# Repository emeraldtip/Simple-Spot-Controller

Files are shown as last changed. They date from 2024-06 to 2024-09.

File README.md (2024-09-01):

# Simple Spot Controller
A small, very basic and simple to use Arduino-based DMX spot light controller.
Made to control 6 Cameo TS 60 W RGBW WH theatre spotlights at my school for ceremonial events.
Currently allows you to adjust brightess and temperature of RGBW spotlights with a master dimmer channel.

## Materials used
- 1x Cheap knockoff Arduino (USB type B 2.0 port, ATmega328P CH340 and some extra pin holes next to ICSP pins (GND and 5V for easier soldering))

  Knockoff arduino

- 2x square ACP 47K potentiometers with a rectangular hole stolen from old in-floor heating controller (resistance doesn't really matter much on arduino, you could use any resistance pot just smaller resistance pots use more power)

  ACP potentiometer

- 1x MAX485 chip (as one wasn't available near me and the size is too small to solder to easily without a breakout board, so I bought a cheap USB-RS485 Adapter and soldered wires to the MAX485 on there)
- Female end of an XLR cable
- Wires
- 3D printer plastic (multicolor if you want to be fancy)
- Some small screws (you can screw M3 screws into the posts on the lid or use wood screws or something)

## Code
The code uses the DmxSimple arduino library to write DMX values and just reads potentiometer values to control the global dimmer brightness and the RGB channel values, which shift the color temp of the lights.

## Wiring
This fritzing image pretty much sums it up.

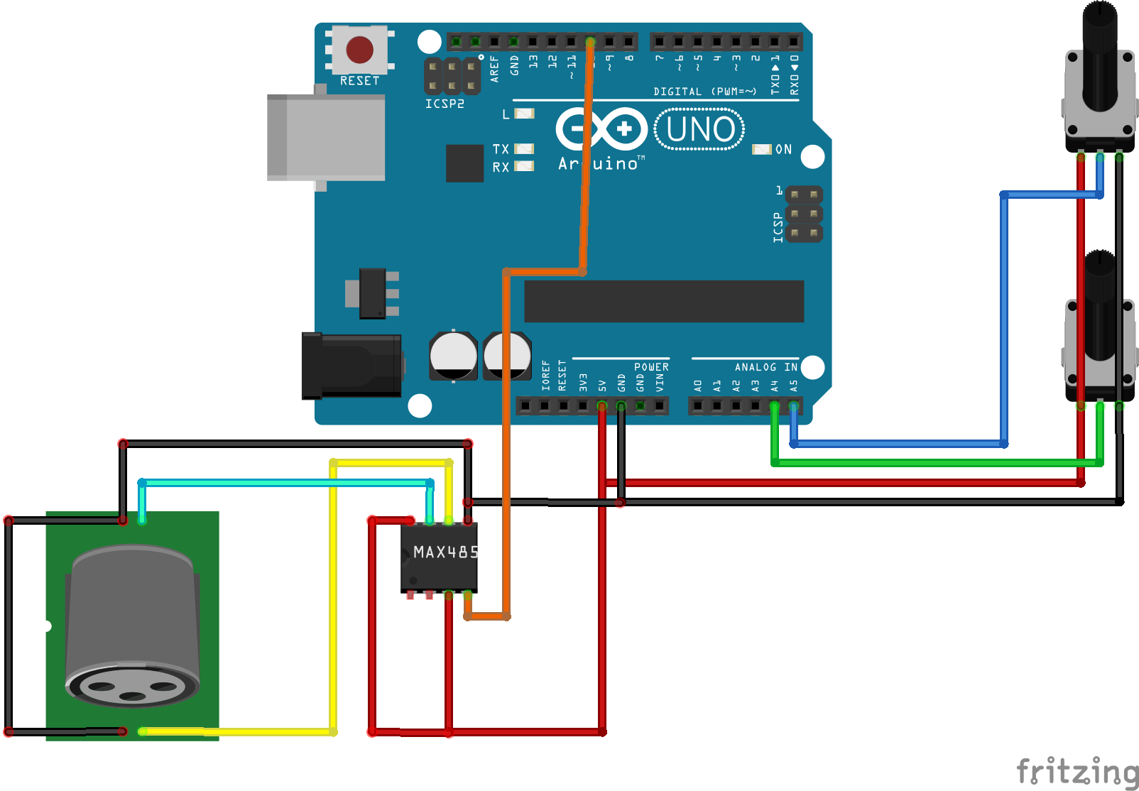
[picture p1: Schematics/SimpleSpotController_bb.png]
Fritzing schematic


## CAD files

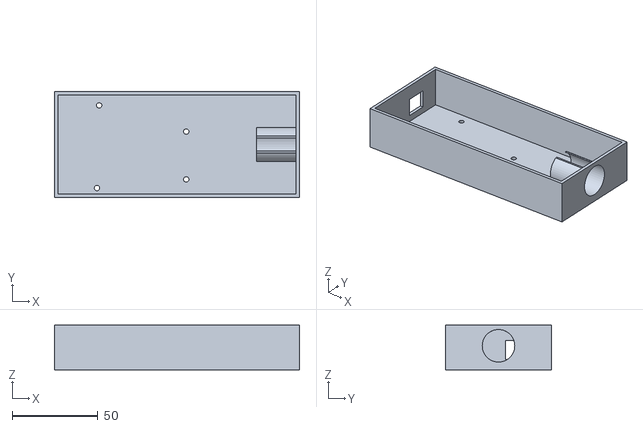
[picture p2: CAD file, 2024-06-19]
Models/Main box.stl
143.0 x 62.0 x 26.0

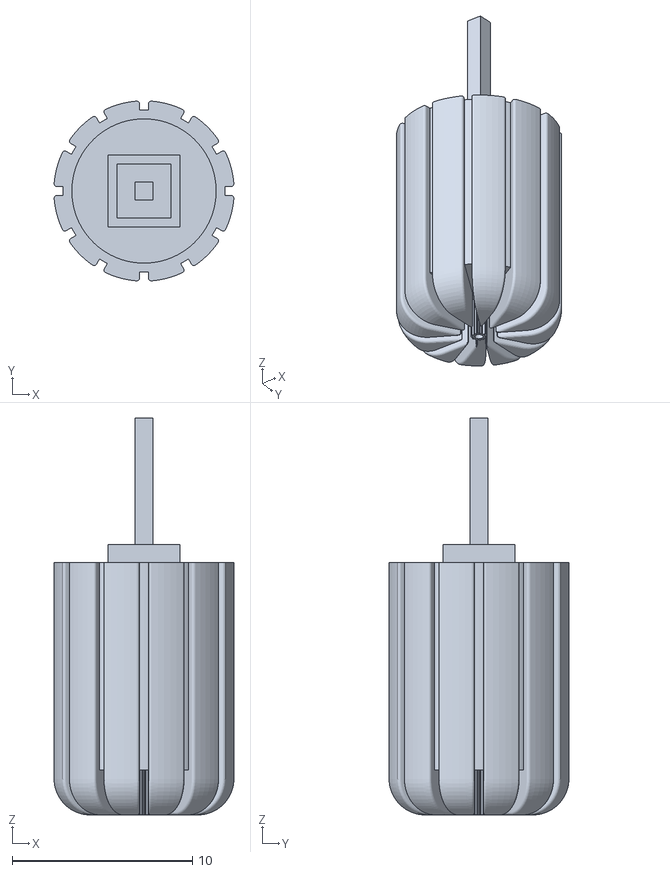
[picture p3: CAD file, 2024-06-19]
Models/Knob top.stl
9.97 x 9.97 x 22.0

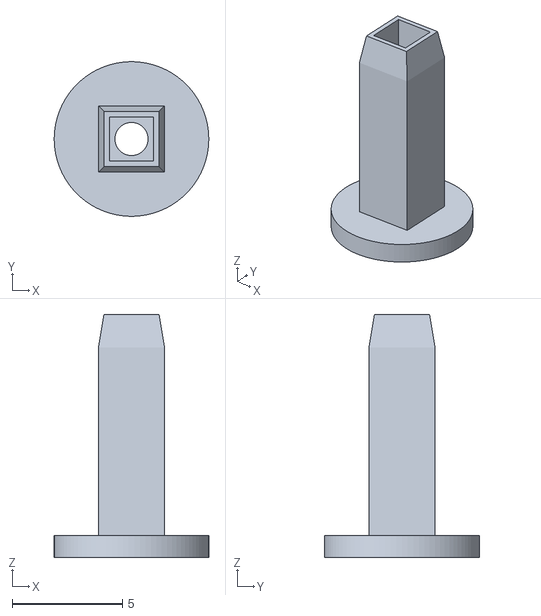
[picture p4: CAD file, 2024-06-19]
Models/Knob bottom.stl
7.00 x 7.00 x 11.0

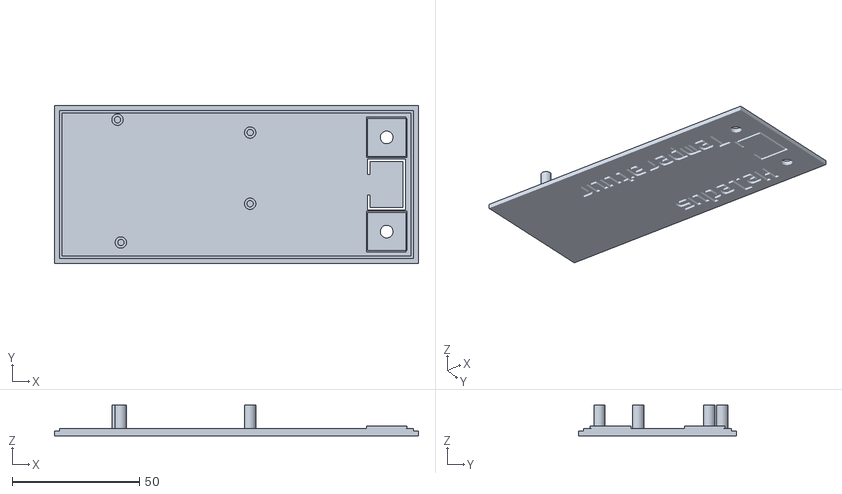
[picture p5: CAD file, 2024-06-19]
Models/Lid.stl
143.0 x 62.0 x 12.2

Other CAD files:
Models/SimpleSpotController box.f3d

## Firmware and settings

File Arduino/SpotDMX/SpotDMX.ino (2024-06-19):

#include <DmxSimple.h>

void setup() {
  pinMode(A5,INPUT);
  pinMode(A4,INPUT);
  DmxSimple.usePin(10);
}


void loop() {
  //potentiometer reading and correcting
  int val1 = map(analogRead(A4),0,1023,255,-1);
  int bright = constrain(val1,0,255);
  
  int val2 = map(analogRead(A5),0,1023,255,-1);
  int temp = constrain(val2,0,255);

  int tempy = constrain((temp-133)*2,0,255); //yellow temp (number 133 to eliminate flickering when transitioning form yellow to blue)
  int tempb = constrain((122-temp)*2,0,255); //blue temp (same here with the number 122) 

  
  for (int i = 0; i<6; i++) {
    //Dimmer
    DmxSimple.write(1+5*i,bright);
    //Red and green
    DmxSimple.write(2+5*i,tempy);
    DmxSimple.write(3+5*i,tempy);
    //Blue
    DmxSimple.write(4+5*i,tempb);

    //White
    DmxSimple.write(5+5*i,255);
  }

  //Black out rest of the channels
  for (int i = 31; i<256; i++)
  {
    DmxSimple.write(i,0);
  }
}

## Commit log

2024-06-19 Added schematics
    [SimpleSpotController.fzz]
2024-06-19 Added wiring section to readme
